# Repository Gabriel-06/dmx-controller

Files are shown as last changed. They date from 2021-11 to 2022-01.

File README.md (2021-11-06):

# DMX Controller
## The Boards 
### Board 2 Revision A
In revision A (REV A) the `S̅R̅C̅L̅R̅` pin on the shift register is pulled HIGH, this keeps the shift registers in a constantly cleared state. I thought that the issue was with the output enable pin (`O̅E̅`) as I said in my AT2, but this wasn’t the issue. I’m not even sure where that came from as the correction that I made to my board was on the right pin (`S̅R̅C̅L̅R̅`). In REV A, the NPN transistors to properly drive the 7-segment display are also missing. In order to use this revision, 2 cuts must be made as shown to cut the `S̅R̅C̅L̅R̅` pin from the ground plane. A wire can then be soldered directly onto the pin of the shift register that goes to an exposed +5V source. 2 possibilities for this are shown on the image below. In this revision the ICSP header is also flipped so the connector pinout is only correct on the back of the board, even though the silkscreen shows that the connector should be on the front. This is fixed in later revisions (I think). In this revision, for it to be bus powered (powered from USB) a wire needs to be soldered in from the fuse of the USB to the +5V port on the other side of the board (also in the image below, the white wire). Solder to the side after the fuse, as then it still gives you the protection. 

### Board 2 Revision B
In revision B (REV B), the same mistake exists regarding the `S̅R̅C̅L̅R̅` pin, except this time the output enable pin is wrongly pulled HIGH as well. 1 step forward, 2 steps back. So, for the revision B board, 3 points need to be cut, as outlined in the image below. Cut 1 is to cut the +5V rail going to the `O̅E̅` pin on the shift register. Cuts 2 and 3 are both to cut the `S̅R̅C̅L̅R̅` pin from the ground plane. This cut leaves you with a small floating ground plane island, but it shouldn’t really matter, there isn’t anything that sensitive around it. For all 3 cuts, you can simply use a small X-Acto knife or Stanley knife to cut the trace, similar to how you might on a strip board. 2 wires then have to be soldered directly onto the pins of the shift register going to an exposed +5V and GND point. I recommend using the exposed power input/output, as that isn’t used at all in the current design.

### Board 2 Revision C
Revision C (REV C) should have hopefully fixed all the issues, although I’m not going to order them, I’m happy just to keep the wires there. The files for it are in the GitHub if you would like to produce your own batch. No guarantees though….

### Board 1 Revision A
Similar to board 2, in revision A (REV A) of this board, the `S̅R̅C̅L̅R̅` pin on the shift registers are pulled HIGH, this keeps the shift registers in a constantly cleared state. 2 cuts need to make in the positions shown on the image below. A wire then has to be soldered directly onto the pin of the shift register and connected to a +5V source. The most convenient for me was the interconnect’s +5V line, as shown in the image below. 

### Board 1 Revision B
Revision B (REV B) should hopefully have fixed the issue. I’m not going to order any boards of this revision, but the files for it are in the GitHub, if you need to order anymore, or need it for reference.

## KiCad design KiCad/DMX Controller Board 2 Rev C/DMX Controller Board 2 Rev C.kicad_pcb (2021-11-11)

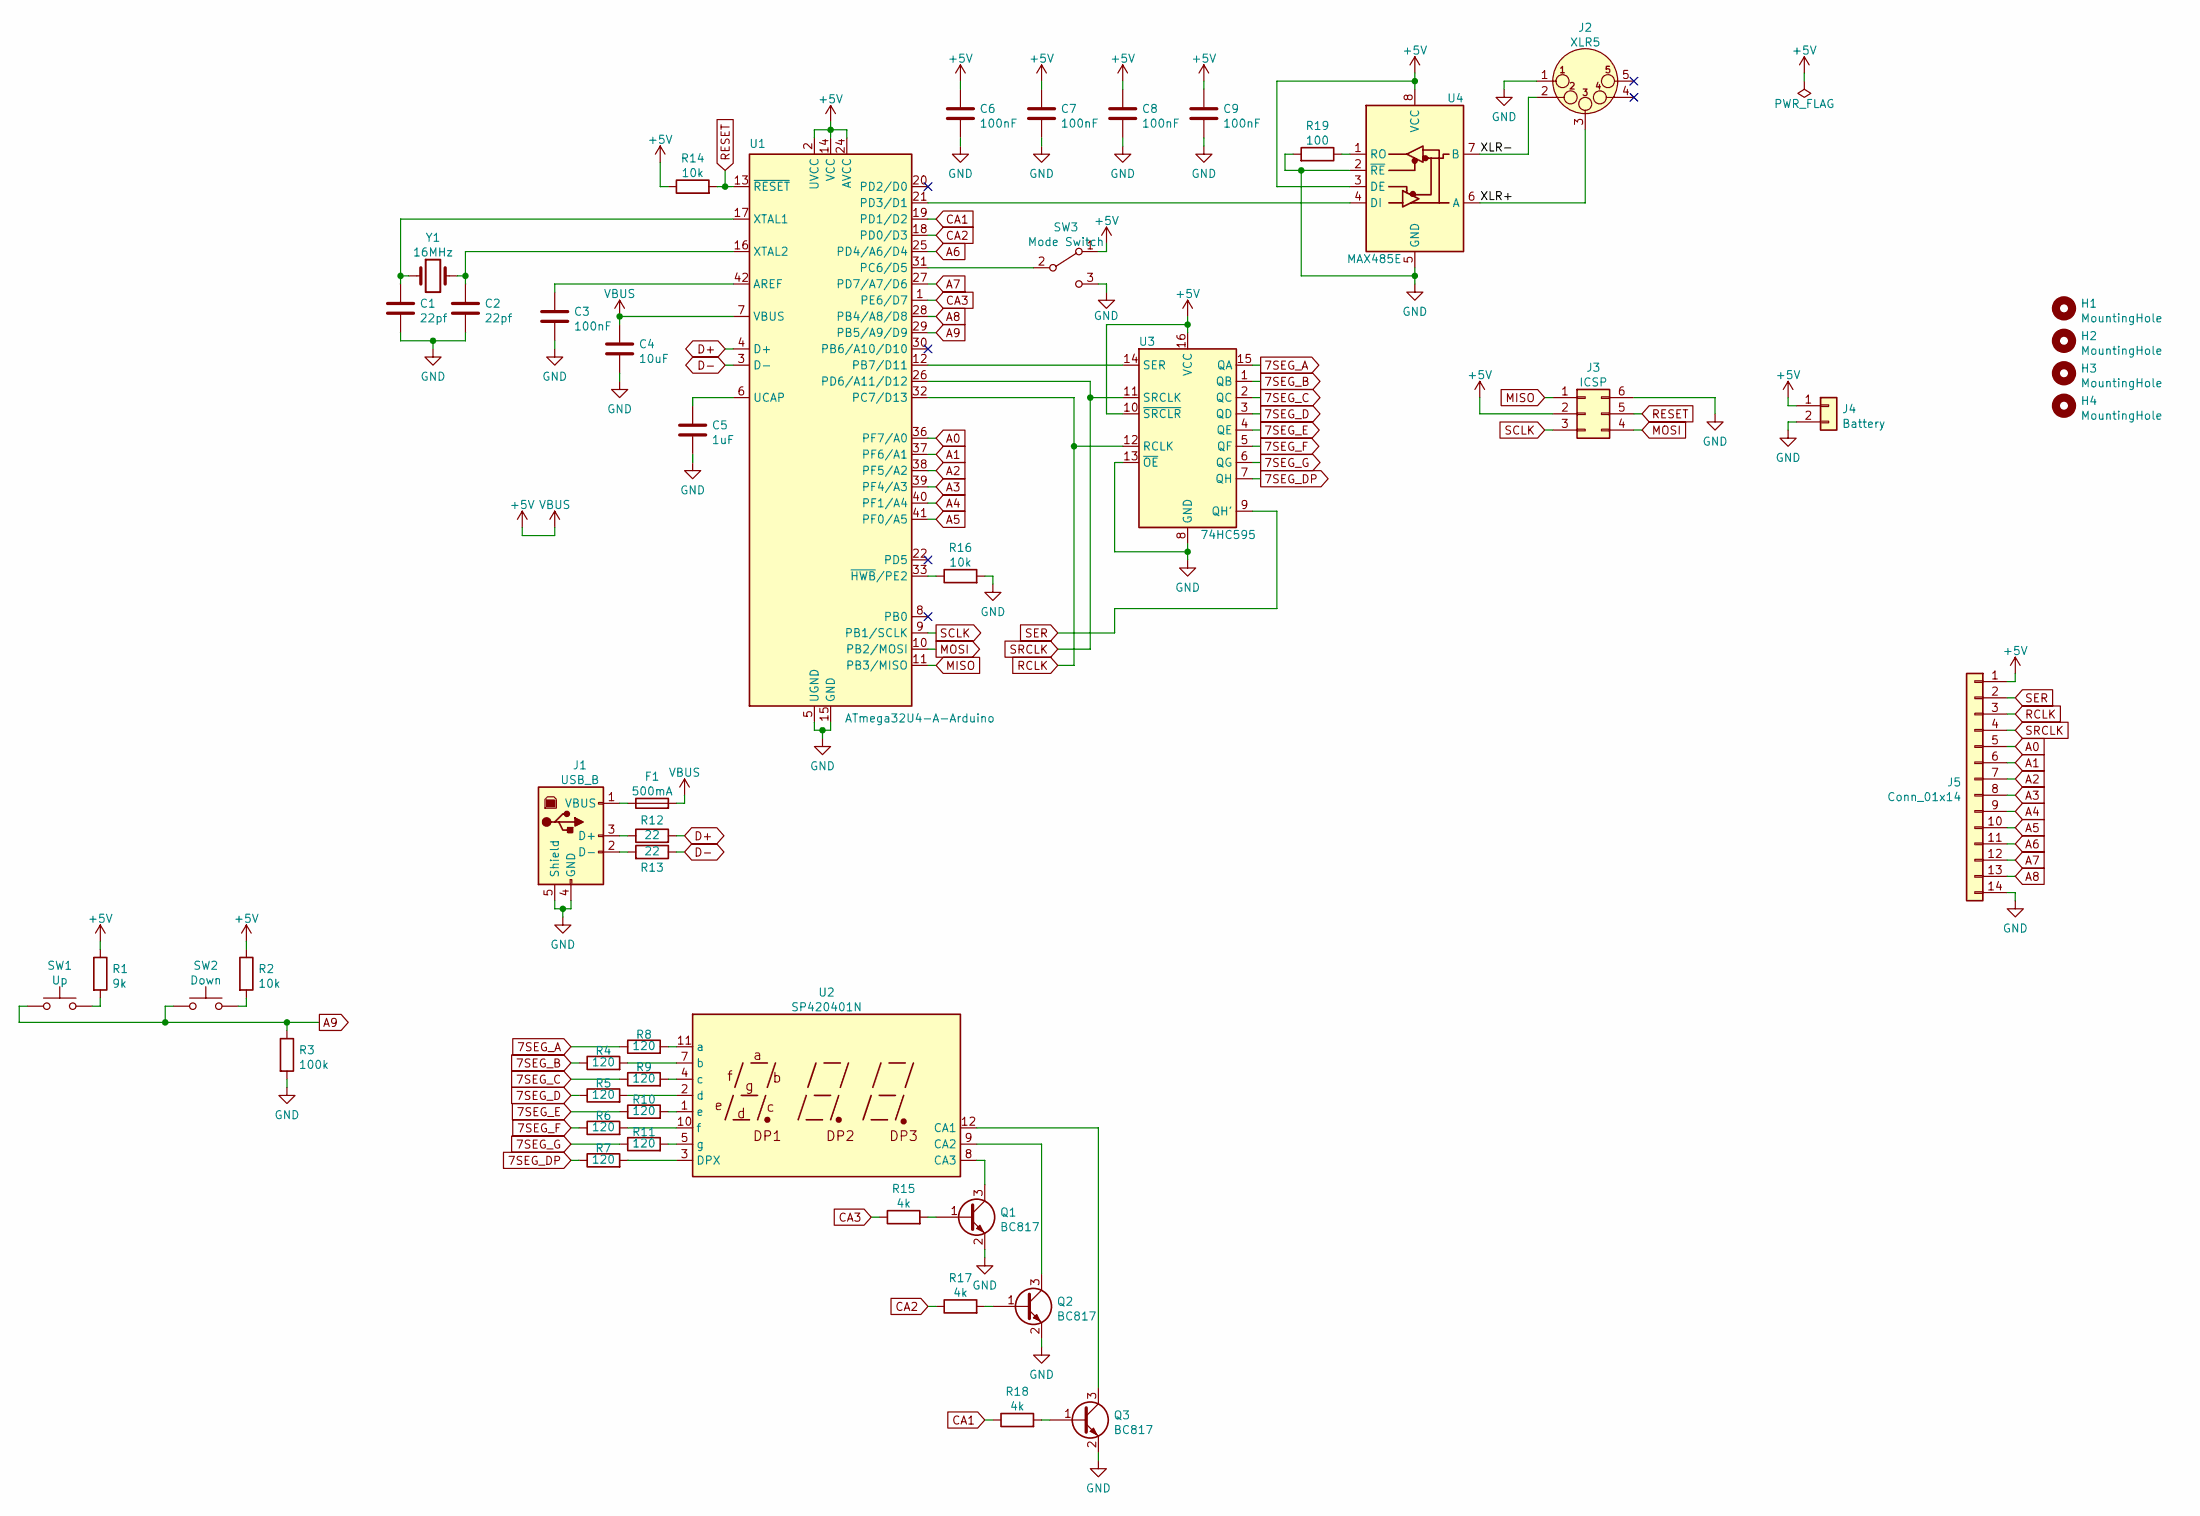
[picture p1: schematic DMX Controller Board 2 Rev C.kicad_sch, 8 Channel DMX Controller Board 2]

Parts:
C1, C2: 22pf; C_0805_2012Metric_Pad1.18x1.45mm_HandSolder
C3, C6, C7, C8, C9: 100nF; C_0805_2012Metric_Pad1.18x1.45mm_HandSolder
C4: 10uF; C_0805_2012Metric_Pad1.18x1.45mm_HandSolder
C5: 1uF; C_0805_2012Metric_Pad1.18x1.45mm_HandSolder
F1: 500mA; Fuse_1206_3216Metric_Pad1.42x1.75mm_HandSolder
H1, H2, H3, H4: MountingHole; MountingHole_3.2mm_M3
J1: USB_B; USB_B_USB-B02
J2: XLR5; PinHeader_1x03_P2.54mm_Vertical
J3: ICSP; PinSocket_2x03_P2.54mm_Vertical
J4: Battery; PinSocket_1x02_P2.54mm_Vertical
J5: Conn_01x14; PinSocket_1x14_P2.54mm_Vertical
Q1, Q2, Q3: BC817; SOT-23
R1: 9k; R_0805_2012Metric_Pad1.20x1.40mm_HandSolder
R2, R14, R16: 10k; R_0805_2012Metric_Pad1.20x1.40mm_HandSolder
R3: 100k; R_0805_2012Metric_Pad1.20x1.40mm_HandSolder
R4, R5, R6, R7, R8, R9, R10, R11: 120; R_0805_2012Metric_Pad1.20x1.40mm_HandSolder
R12, R13: 22; R_0805_2012Metric_Pad1.20x1.40mm_HandSolder
R15, R17, R18: 4k; R_0805_2012Metric_Pad1.20x1.40mm_HandSolder
R19: 100; R_0805_2012Metric_Pad1.20x1.40mm_HandSolder
SW1: Up; SW_PUSH_6mm_H13mm
SW2: Down; SW_PUSH_6mm_H13mm
SW3: Mode Switch; PinHeader_1x03_P2.54mm_Vertical
U1: ATmega32U4-A-Arduino; TQFP-44_10x10mm_P0.8mm
U2: SP420401N
U3: 74HC595; SOP-16_3.9x9.9mm_P1.27mm
U4: MAX485E; SOP-8_3.9x4.9mm_P1.27mm
Y1: 16MHz; Crystal_HC49-4H_Vertical

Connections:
7SEG_A: R8.1, U3.15 (QA)
7SEG_B: R4.1, U3.1 (QB)
7SEG_C: R9.1, U3.2 (QC)
7SEG_D: R5.1, U3.3 (QD)
7SEG_DP: R7.1, U3.7 (QH)
7SEG_E: R10.1, U3.4 (QE)
7SEG_F: R6.1, U3.5 (QF)
7SEG_G: R11.1, U3.6 (QG)
+5V: C4.1, C6.1, C7.1, C8.1, C9.1, F1.2, J3.2, J4.1, J5.1, R1.1, R2.1, R14.1, SW3.1 (A), U1.2 (UVCC), U1.7 (VBUS), U1.14 (VCC), U1.24 (AVCC), U1.34 (VCC), U1.44 (AVCC), U3.10 (~SRCLR), U3.16 (VCC), U4.3 (DE), U4.8 (VCC)
/XLR+: J2.3, U4.6 (A)
/XLR-: J2.2, U4.7 (B)
A0: J5.5, U1.36 (PF7/A0)
A1: J5.6, U1.37 (PF6/A1)
A2: J5.7, U1.38 (PF5/A2)
A3: J5.8, U1.39 (PF4/A3)
A4: J5.9, U1.40 (PF1/A4)
A5: J5.10, U1.41 (PF0/A5)
A6: J5.11, U1.25 (PD4/A6/D4)
A7: J5.12, U1.27 (PD7/A7/D6)
A8: J5.13, U1.28 (PB4/A8/D8)
A9: R3.1, SW1.1, SW2.1, U1.29 (PB5/A9/D9)
CA1: R18.1, U1.19 (PD1/D2)
CA2: R17.1, U1.18 (PD0/D3)
CA3: R15.1, U1.1 (PE6/D7)
D+: R12.2, U1.4 (D+)
D-: R13.1, U1.3 (D-)
GND: C1.2, C2.2, C3.2, C4.2, C5.2, C6.2, C7.2, C8.2, C9.2, J1.4 (GND), J1.5 (Shield), J2.1, J3.6, J4.2, J5.14, Q1.2 (E), Q2.2 (E), Q3.2 (E), R3.2, R16.2, R19.2, SW3.3 (C), U1.5 (UGND), U1.15 (GND), U1.23 (GND), U1.35 (GND), U1.43 (GND), U3.8 (GND), U3.13 (~OE), U4.2 (~RE), U4.5 (GND)
MISO: J3.1, U1.11 (PB3/MISO)
MOSI: J3.4, U1.10 (PB2/MOSI)
unnamed: C1.1, U1.17 (XTAL1), Y1.1
unnamed: C2.1, U1.16 (XTAL2), Y1.2
unnamed: C3.1, U1.42 (AREF)
unnamed: C5.1, U1.6 (UCAP)
unnamed: F1.1, J1.1 (VBUS)
unnamed: J1.2 (D-), R13.2
unnamed: J1.3 (D+), R12.1
unnamed: Q1.1 (B), R15.2
unnamed: Q1.3 (C), U2.8 (CA3)
unnamed: Q2.1 (B), R17.2
unnamed: Q2.3 (C), U2.9 (CA2)
unnamed: Q3.1 (B), R18.2
unnamed: Q3.3 (C), U2.12 (CA1)
unnamed: R1.2, SW1.2
unnamed: R2.2, SW2.2
unnamed: R4.2, U2.7 (b)
unnamed: R5.2, U2.2 (d)
unnamed: R6.2, U2.10 (f)
unnamed: R7.2, U2.3 (DPX)
unnamed: R8.2, U2.11 (a)
unnamed: R9.2, U2.4 (c)
unnamed: R10.2, U2.1 (e)
unnamed: R11.2, U2.5 (g)
unnamed: R16.1, U1.33 (~HWB~/PE2)
unnamed: R19.1, U4.1 (RO)
unnamed: SW3.2 (B), U1.31 (PC6/D5)
unnamed: U1.12 (PB7/D11), U3.14 (SER)
unnamed: U1.21 (PD3/D1), U4.4 (DI)
RCLK: J5.3, U1.32 (PC7/D13), U3.12 (RCLK)
RESET: J3.5, R14.2, U1.13 (~RESET)
SCLK: J3.3, U1.9 (PB1/SCLK)
SER: J5.2, U3.9 (QH')
SRCLK: J5.4, U1.26 (PD6/A11/D12), U3.11 (SRCLK)

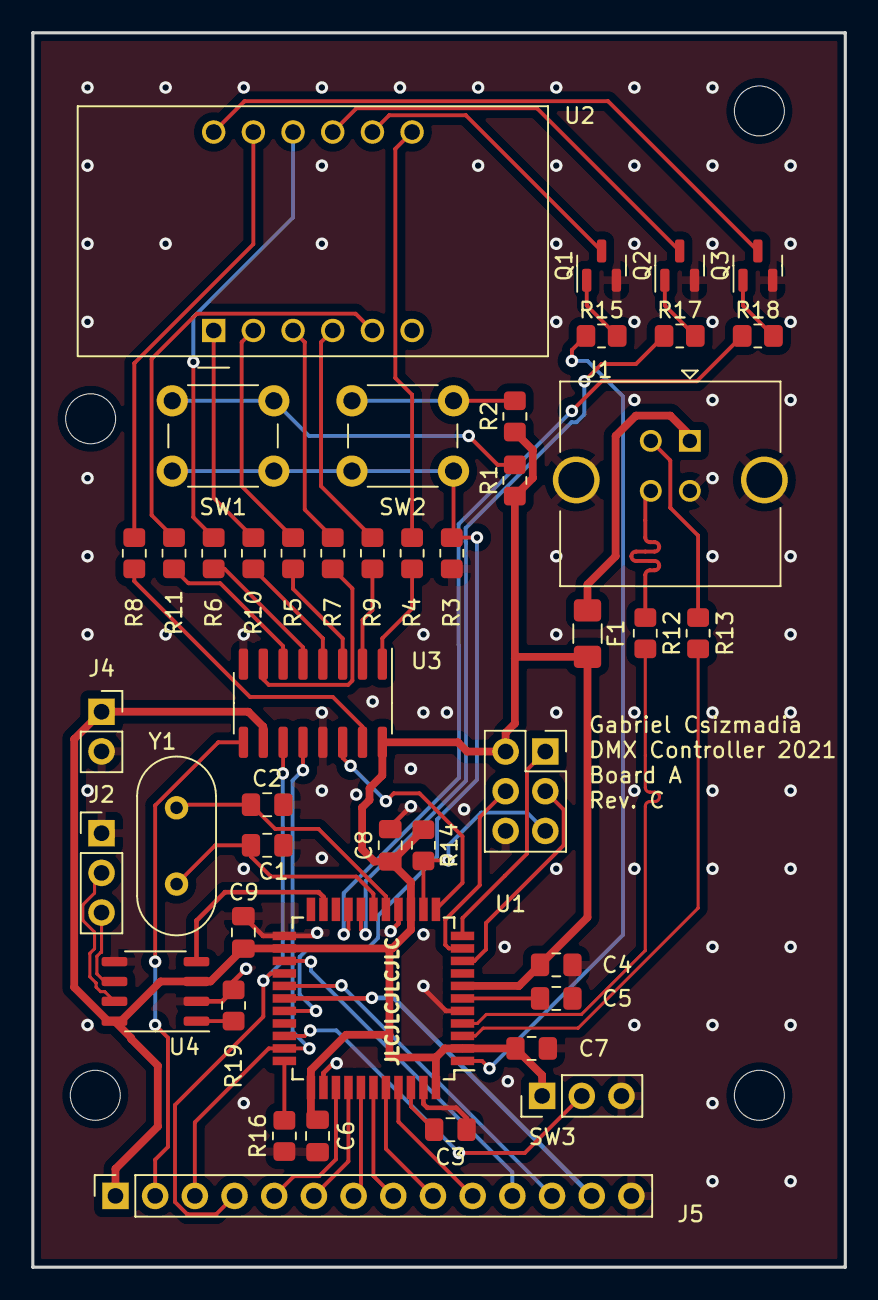
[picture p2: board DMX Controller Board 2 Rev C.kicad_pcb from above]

Board: 2 copper layers, 52.0 x 79.0 mm, 49 parts (0 on the bottom side), 62 nets.

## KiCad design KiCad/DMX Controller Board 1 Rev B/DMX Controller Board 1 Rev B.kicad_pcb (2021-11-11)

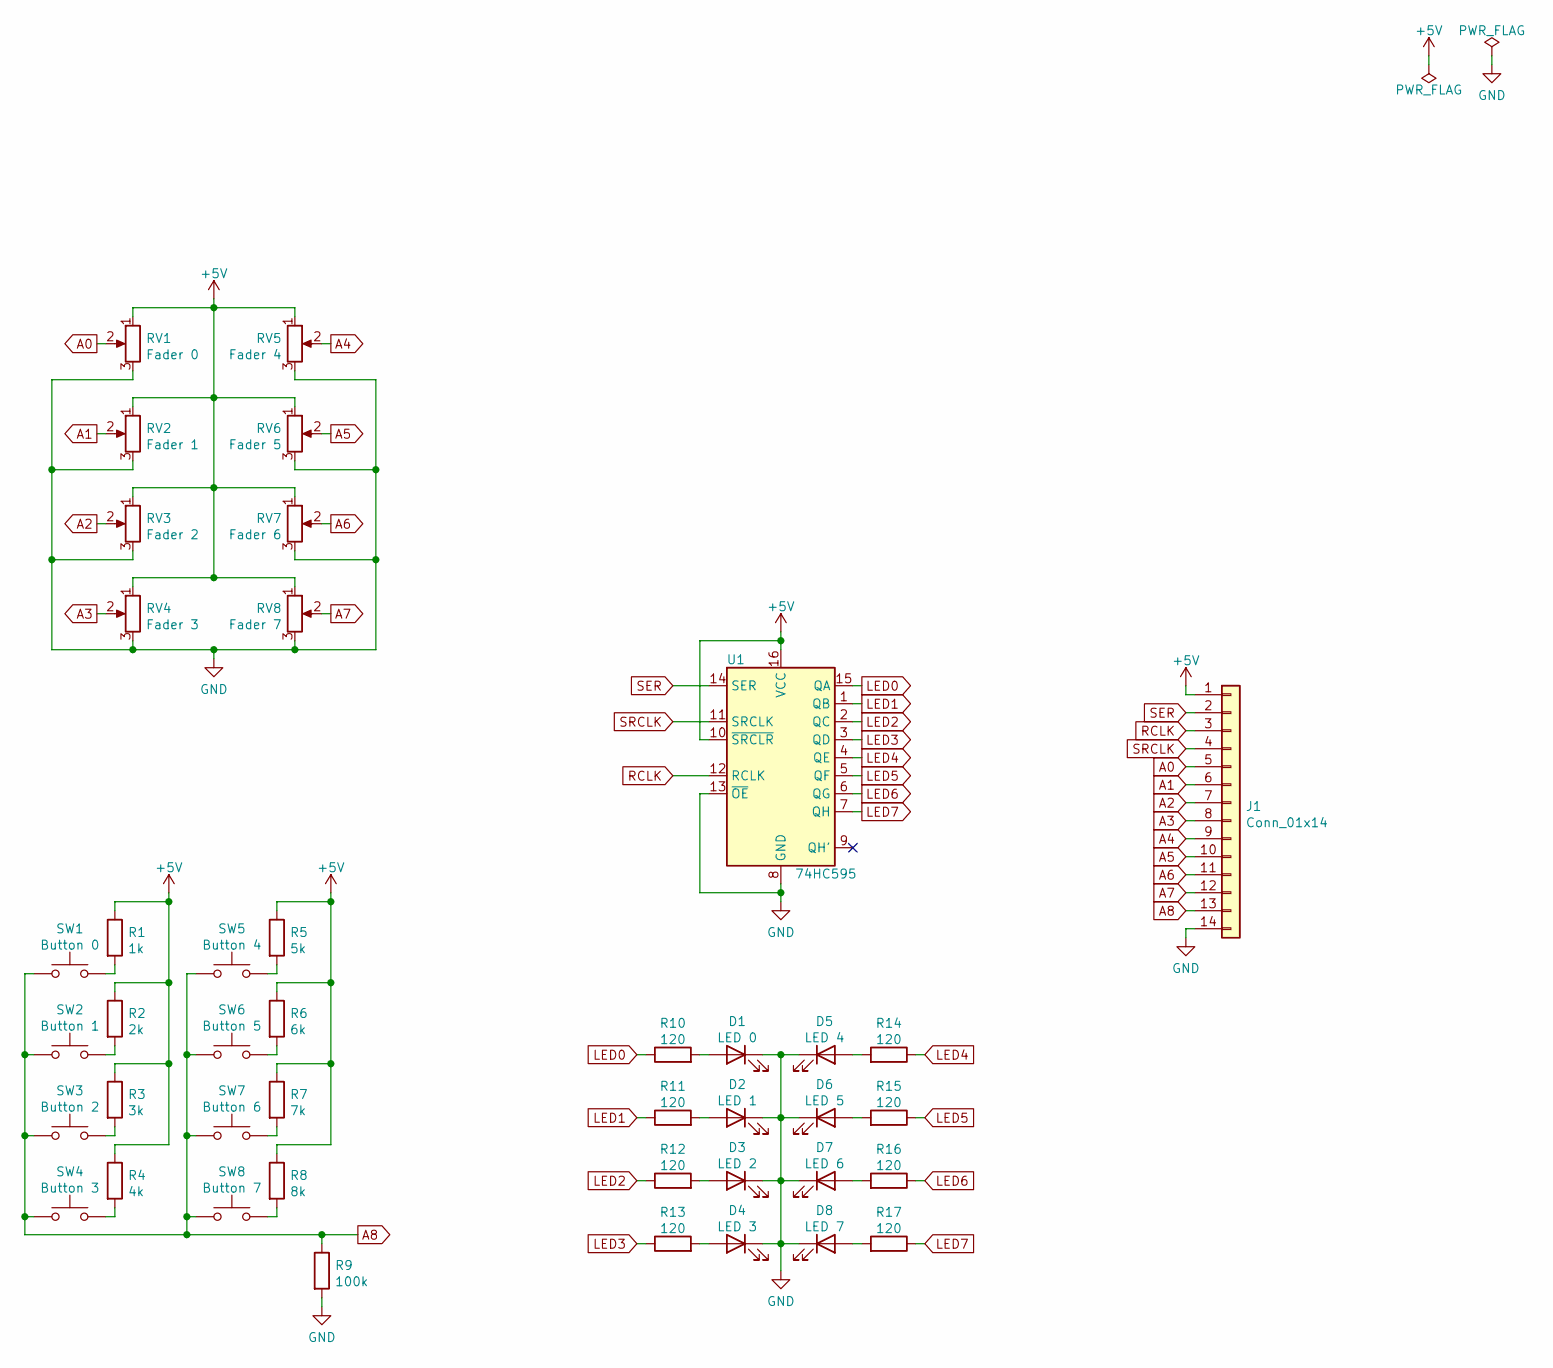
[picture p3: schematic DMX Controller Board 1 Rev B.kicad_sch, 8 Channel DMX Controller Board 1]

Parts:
D1: LED 0; LED_D3.0mm
D2: LED 1; LED_D3.0mm
D3: LED 2; LED_D3.0mm
D4: LED 3; LED_D3.0mm
D5: LED 4; LED_D3.0mm
D6: LED 5; LED_D3.0mm
D7: LED 6; LED_D3.0mm
D8: LED 7; LED_D3.0mm
J1: Conn_01x14; PinSocket_1x14_P2.54mm_Vertical
R1: 1k; R_0805_2012Metric_Pad1.20x1.40mm_HandSolder
R2: 2k; R_0805_2012Metric_Pad1.20x1.40mm_HandSolder
R3: 3k; R_0805_2012Metric_Pad1.20x1.40mm_HandSolder
R4: 4k; R_0805_2012Metric_Pad1.20x1.40mm_HandSolder
R5: 5k; R_0805_2012Metric_Pad1.20x1.40mm_HandSolder
R6: 6k; R_0805_2012Metric_Pad1.20x1.40mm_HandSolder
R7: 7k; R_0805_2012Metric_Pad1.20x1.40mm_HandSolder
R8: 8k; R_0805_2012Metric_Pad1.20x1.40mm_HandSolder
R9: 100k; R_0805_2012Metric_Pad1.20x1.40mm_HandSolder
R10, R11, R12, R13, R14, R15, R16, R17: 120; R_0805_2012Metric_Pad1.20x1.40mm_HandSolder
RV1: Fader 0; Potentiometer_Alps_RS6011SP
RV2: Fader 1; Potentiometer_Alps_RS6011SP
RV3: Fader 2; Potentiometer_Alps_RS6011SP
RV4: Fader 3; Potentiometer_Alps_RS6011SP
RV5: Fader 4; Potentiometer_Alps_RS6011SP
RV6: Fader 5; Potentiometer_Alps_RS6011SP
RV7: Fader 6; Potentiometer_Alps_RS6011SP
RV8: Fader 7; Potentiometer_Alps_RS6011SP
SW1: Button 0; SW_PUSH_6mm_H13mm
SW2: Button 1; SW_PUSH_6mm_H13mm
SW3: Button 2; SW_PUSH_6mm_H13mm
SW4: Button 3; SW_PUSH_6mm_H13mm
SW5: Button 4; SW_PUSH_6mm_H13mm
SW6: Button 5; SW_PUSH_6mm_H13mm
SW7: Button 6; SW_PUSH_6mm_H13mm
SW8: Button 7; SW_PUSH_6mm_H13mm
U1: 74HC595; SOP-16_3.9x9.9mm_P1.27mm

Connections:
+5V: J1.1, R1.1, R2.1, R3.1, R4.1, R5.1, R6.1, R7.1, R8.1, RV1.1, RV2.1, RV3.1, RV4.1, RV5.1, RV6.1, RV7.1, RV8.1, U1.10 (~SRCLR), U1.16 (VCC)
A0: J1.5, RV1.2
A1: J1.6, RV2.2
A2: J1.7, RV3.2
A3: J1.8, RV4.2
A4: J1.9, RV5.2
A5: J1.10, RV6.2
A6: J1.11, RV7.2
A7: J1.12, RV8.2
A8: J1.13, R9.1, SW1.1, SW2.1, SW3.1, SW4.1, SW5.1, SW6.1, SW7.1, SW8.1
GND: D1.1 (K), D2.1 (K), D3.1 (K), D4.1 (K), D5.1 (K), D6.1 (K), D7.1 (K), D8.1 (K), J1.14, R9.2, RV1.3, RV2.3, RV3.3, RV4.3, RV5.3, RV6.3, RV7.3, RV8.3, U1.8 (GND), U1.13 (~OE)
LED0: R10.1, U1.15 (QA)
LED1: R11.1, U1.1 (QB)
LED2: R12.1, U1.2 (QC)
LED3: R13.1, U1.3 (QD)
LED4: R14.1, U1.4 (QE)
LED5: R15.1, U1.5 (QF)
LED6: R16.1, U1.6 (QG)
LED7: R17.1, U1.7 (QH)
unnamed: D1.2 (A), R10.2
unnamed: D2.2 (A), R11.2
unnamed: D3.2 (A), R12.2
unnamed: D4.2 (A), R13.2
unnamed: D5.2 (A), R14.2
unnamed: D6.2 (A), R15.2
unnamed: D7.2 (A), R16.2
unnamed: D8.2 (A), R17.2
unnamed: R1.2, SW1.2
unnamed: R2.2, SW2.2
unnamed: R3.2, SW3.2
unnamed: R4.2, SW4.2
unnamed: R5.2, SW5.2
unnamed: R6.2, SW6.2
unnamed: R7.2, SW7.2
unnamed: R8.2, SW8.2
RCLK: J1.3, U1.12 (RCLK)
SER: J1.2, U1.14 (SER)
SRCLK: J1.4, U1.11 (SRCLK)

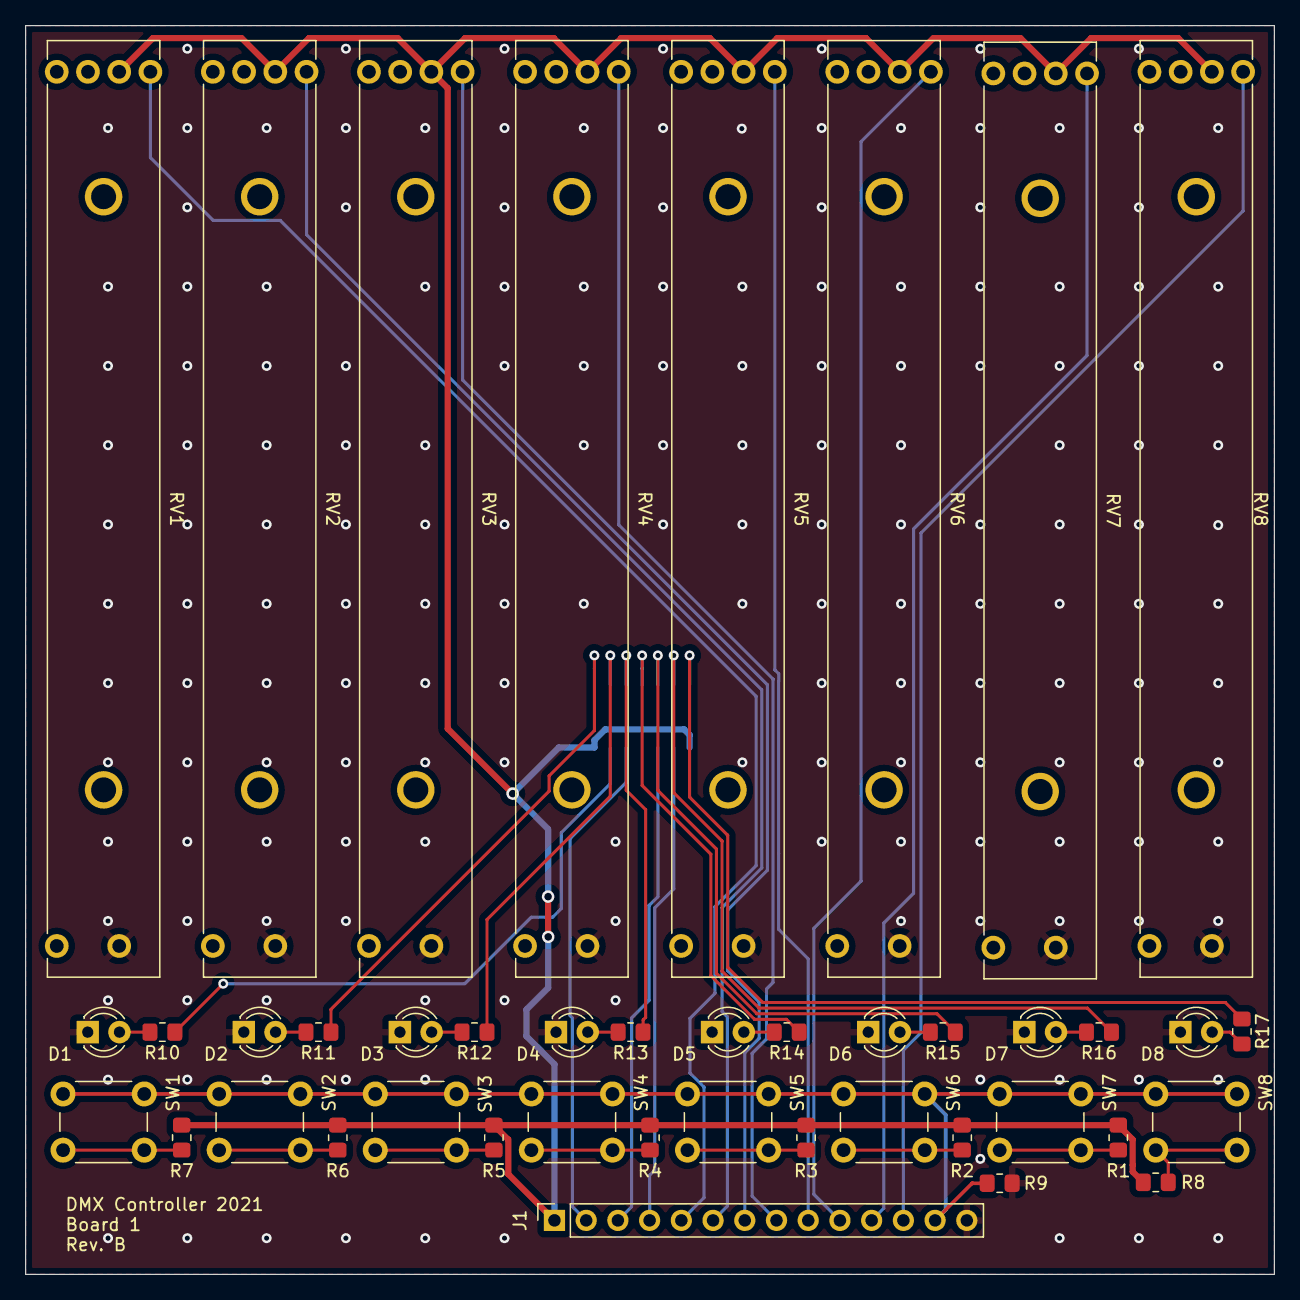
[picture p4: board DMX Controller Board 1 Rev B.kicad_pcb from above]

Board: 2 copper layers, 100.0 x 100.0 mm, 43 parts (1 on the bottom side), 38 nets.

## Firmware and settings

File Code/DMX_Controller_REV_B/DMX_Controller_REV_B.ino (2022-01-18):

/*  Compact 8 Channel DMX Controller
 *   
 *  NOTE: This code is writen to work with revision B and later of board 2
 *  
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
 *  Copyright 2021 Gabriel Csizmadia
 *  Open source at GitHub: https://github.com/Gabriel-06/dmx-controller
 */
 
#include <ShiftRegister74HC595.h>
#include <ArduinoDMX.h>

#define DEBUG //Turn debug code on or off

//Define pins where faders and buttons are connected
#define fader0 A0
#define fader1 A1
#define fader2 A2
#define fader3 A3
#define fader4 A4
#define fader5 A5
#define fader6 A6
#define fader7 A7
#define buttons A8

#define CA1 2
#define CA2 3
#define CA3 7

//Define pins for shift register
#define serialDataPin 11
#define clockPin 12
#define latchPin 13

#define countOf(a) (sizeof(a) / sizeof(a[0])) //Function to get count of items in arry
#define universeSize 8 //Set the size of the created DMX universe


byte num[] = {
  B01111110, // Zero
  B00110000, // One
  B01101101, // Two
  B01111001, // Three
  B00110011, // Four
  B01011011, // Five
  B01011111, // Six
  B01110000, // Seven
  B01111111, // Eight
  B01111011, // Nine
};

int buttonValue = 0; //int used to store which button is pressed

int faders[] = {fader0, fader1, fader2, fader3, fader4, fader5, fader6, fader7}; //Array for storing pins of faders
int levels[] = {0, 0, 0, 0, 0, 0, 0, 0}; //Array for storing level of all faders
int channels[] = {1, 2, 3, 4, 5, 6, 7, 8}; //Array for storing which DMX channels to send to
bool flash[] = {false, false, false, false, false, false, false, false}; //Array for storing state of flash buttons


ShiftRegister74HC595<2> leds(serialDataPin, clockPin, latchPin); //Initialize shift registers

void setup() {

  DMX.begin(universeSize); //Begin DMX universe with size defined above

#ifdef DEBUG
  Serial.begin(115200); //Begin serial for debugging
#endif

  for (int i = 0; i < countOf(faders); i++) { //Set all faders to inputs
    pinMode(faders[i], INPUT);
  }
}

void loop() {
  for (int i = 0; i < countOf(flash); i++) { //Reset flash value to false each loop and turn off LEDs
    leds.setNoUpdate(i + 8, LOW);
    if (flash[i]) {
      flash[i] = false;
    }
  }

  buttonValue = analogRead(buttons); //Read buttons to see which, if any, are pressed
  if (buttonValue > 800) {
    switch (buttonValue) {
      case 1009 ... 1017:
        flash[0] = true;
        leds.setNoUpdate(8, HIGH);
        break;
      case 999 ... 1007:
        flash[1] = true;
        leds.setNoUpdate(9, HIGH);
        break;
      case 989 ... 997:
        flash[2] = true;
        leds.setNoUpdate(10, HIGH);
        break;
      case 981 ... 988:
        flash[3] = true;
        leds.setNoUpdate(11, HIGH);
        break;
      case 969 ... 977:
        flash[4] = true;
        leds.setNoUpdate(12, HIGH);
        break;
      case 961 ... 968:
        flash[5] = true;
        leds.setNoUpdate(13, HIGH);
        break;
      case 952 ... 960:
        flash[6] = true;
        leds.setNoUpdate(14, HIGH);
        break;
      case 943 ... 951:
        flash[7] = true;
        leds.setNoUpdate(15, HIGH);
        break;
    }
  }

  for (int i = 0; i < countOf(faders); i++) { //Read the status of all faders and map between 0-255 for DMX
    levels[i] = analogRead(faders[i]);
    
    if (levels[i] > 2) { //If level is higher than 2 turn on corresponding LED
      leds.setNoUpdate(8 + i, HIGH);
    }
    
    levels[i] = map(levels[i], 0, 1023, 0, 255);
  }

  leds.updateRegisters(); //Update the shift registers with the correct status for all LEDs
  
  DMX.beginTransmission(); //Begin the DMX transmission

  for (int i = 0; i < countOf(levels); i++) {
    if (flash[i]) {
      DMX.write(channels[i], 255); //If flash is pressed set DMX channel to max
    }
    else {
      DMX.write(channels[i], levels[i]); //Set the level for all 8 DMX channels
    }
  }

  DMX.endTransmission(); //End the DMX transmission

  // START DEBUG
#ifdef DEBUG
  Serial.print("      Levels: "); //Print the levels faders are set at for debuging
  for (int i = 0; i < countOf(levels); i++) {
    Serial.print(levels[i]);
    Serial.print("  ");
  }

  Serial.println("");

  Serial.print("Flash states: "); //Print the flash status for each channel are set at for debuging
  for (int i = 0; i < countOf(levels); i++) {
    Serial.print(flash[i]);
    Serial.print("  ");
  }

  Serial.println("");
#endif
  // DEBUG END

  delay(100); //Slight delay in order not to overload the Arduino
}

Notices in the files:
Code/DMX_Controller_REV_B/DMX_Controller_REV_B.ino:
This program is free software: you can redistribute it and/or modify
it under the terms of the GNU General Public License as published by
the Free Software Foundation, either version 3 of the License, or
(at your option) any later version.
